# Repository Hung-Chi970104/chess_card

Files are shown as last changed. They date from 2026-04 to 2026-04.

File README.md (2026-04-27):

# Pico Chess Card
Ever think of playing chess on the size of a business card? Welcome to the Pico Chess Card!

After building my Tic-Tac-Toe business card, I decided to build a more advanced version that allows users to play chess, compete online through radio, and even compete against AI!

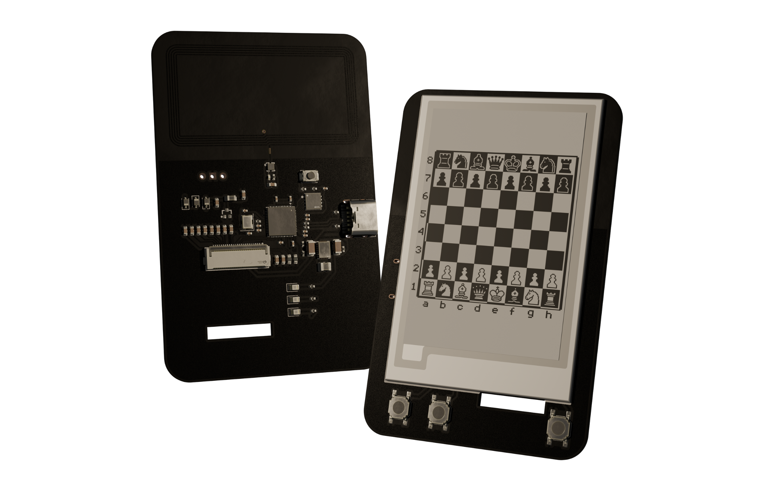
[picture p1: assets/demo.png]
demo


https://github.com/user-attachments/assets/676e2b21-aca0-44f8-8b26-b48a64608b89

# Features
- Pass-and-play mode (like one device but two people take turn)
- Online 1v1 through nrf24l01 (*Will be added in V2!)
- NFC tap to either go to websites or pairing mode

# Components
- RP2040
- 12MHz Crystal (ABM8-272-T3)
- 8MB Flash Storage (W25Q64JVXGIQ)
- Buck-Boost Switching Regulator (RT6150B)
- USB-C (TYPE-C-31-M-12)

# PCB Designs
- 2 layers
- Single-sided component placement
- 2.6mm board thickness
- HASL (with lead) surface finish
- 1oz outer copper weight

## PCB Schematic
schemtatic

## PCB Layouts
pcb_front
pcb_back
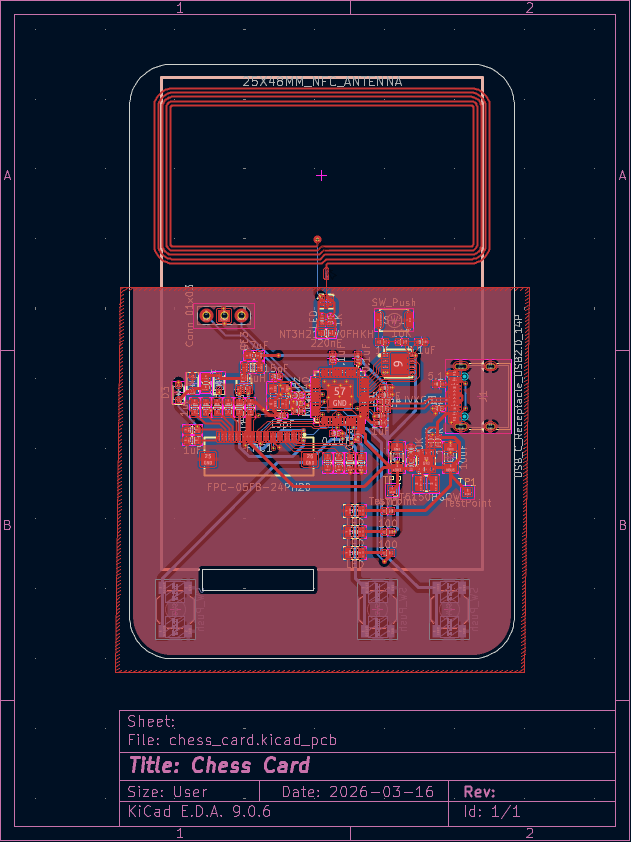
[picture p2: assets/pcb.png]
pcb_design


## 3D Model
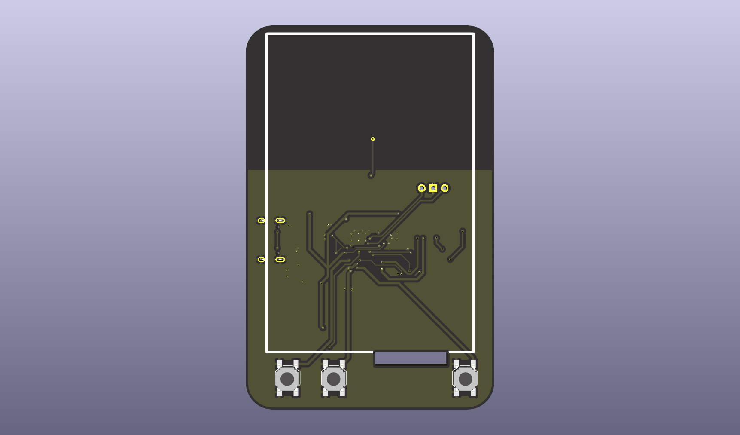
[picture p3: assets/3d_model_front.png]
3d_model_front

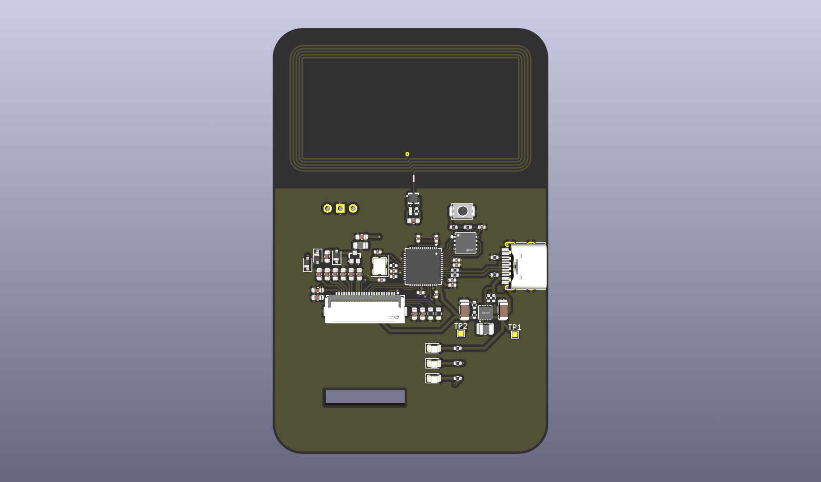
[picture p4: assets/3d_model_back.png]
3d_model_back


# How to order
- Download the zip file
- Upload the zip file to JLCPCB
- Select PCBA and continue
- Upload BOM.csv and position.csv
- Select the parts and submit payment

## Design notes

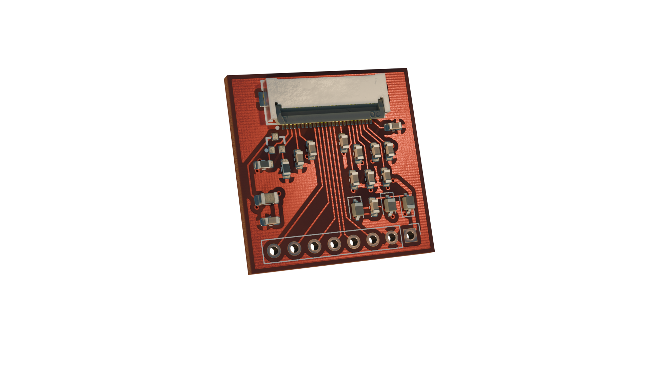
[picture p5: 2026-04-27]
e_ink_screen_module/e_ink_screen_module.png

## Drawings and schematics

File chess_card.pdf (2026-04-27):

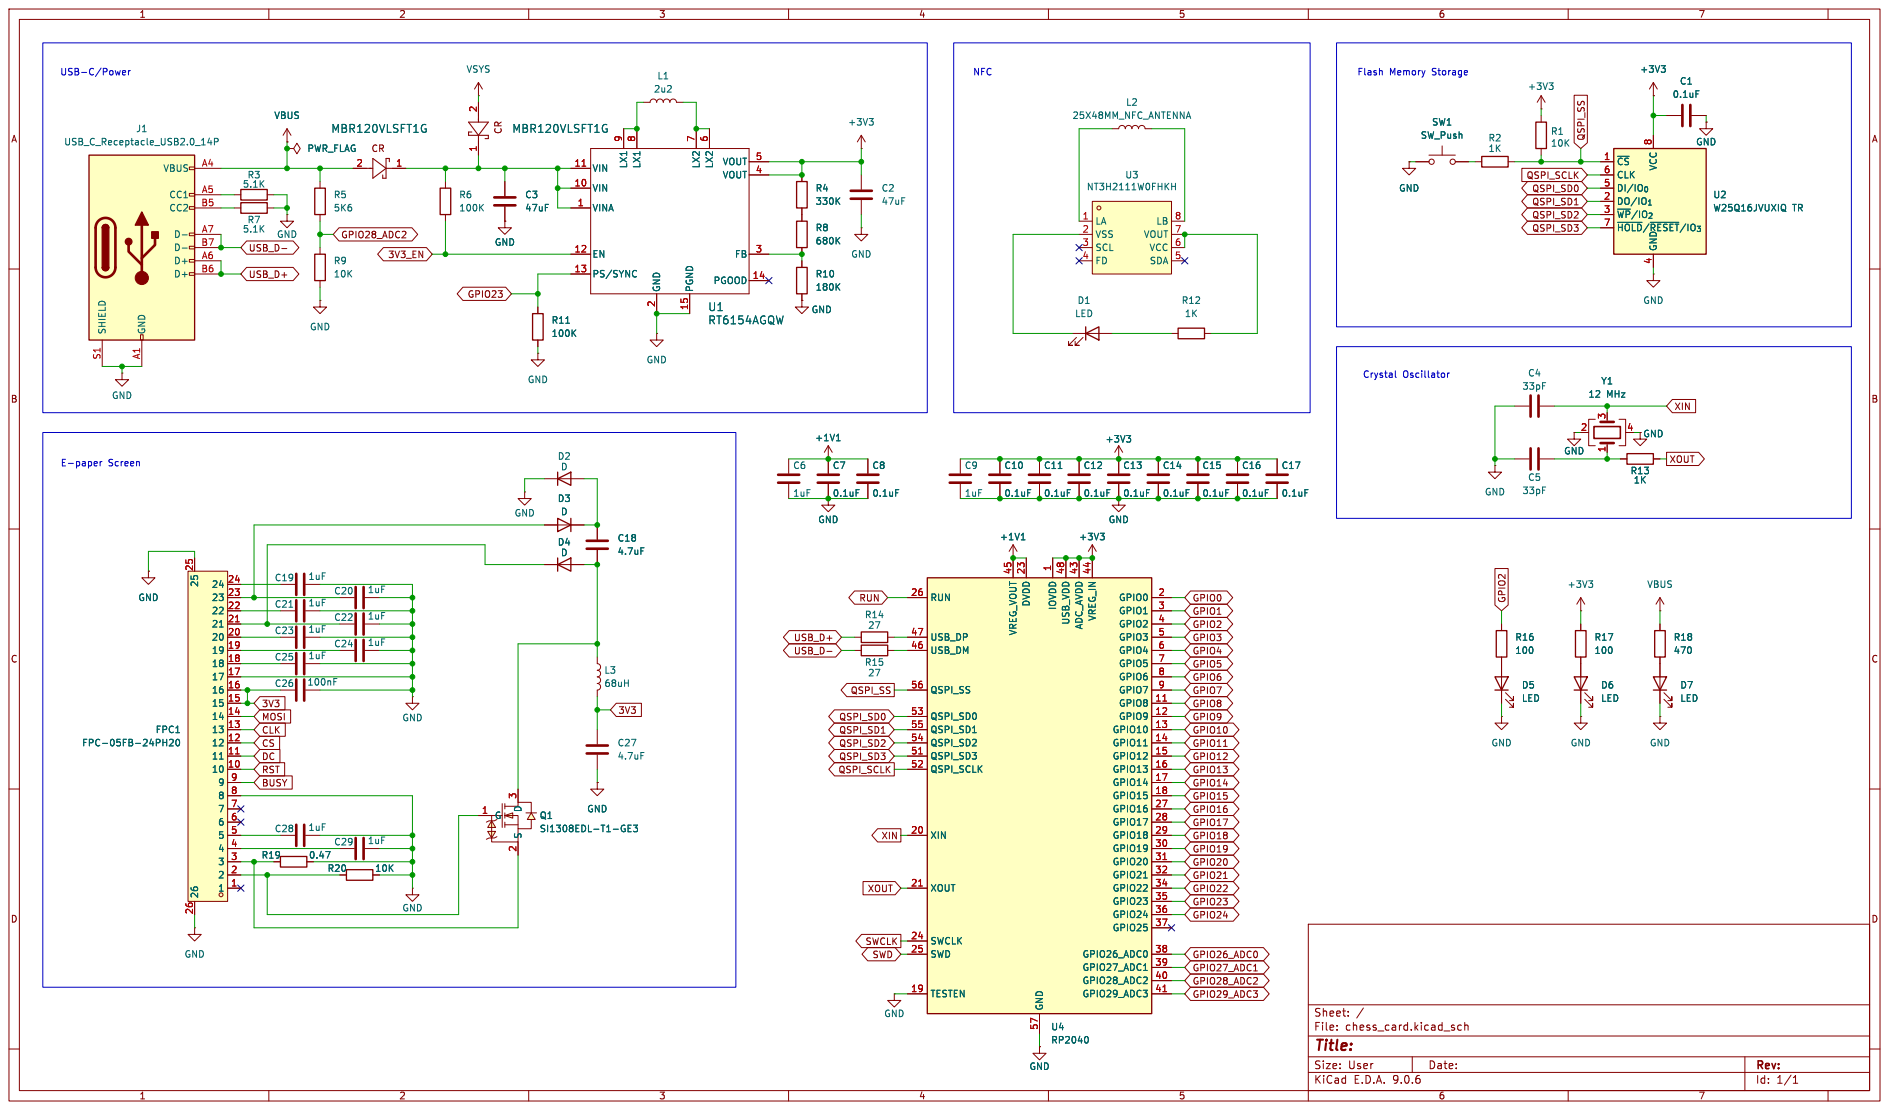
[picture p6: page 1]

6 VOUT 5 VOUT 4 FB 3 PGOOD 14 U1 RT6154AGQW

6 VOUT 5 VOUT 4 FB 3 PGOOD 14 R8

Id: 1/1 Title: File: chess_card.kicad_sch Sheet: /

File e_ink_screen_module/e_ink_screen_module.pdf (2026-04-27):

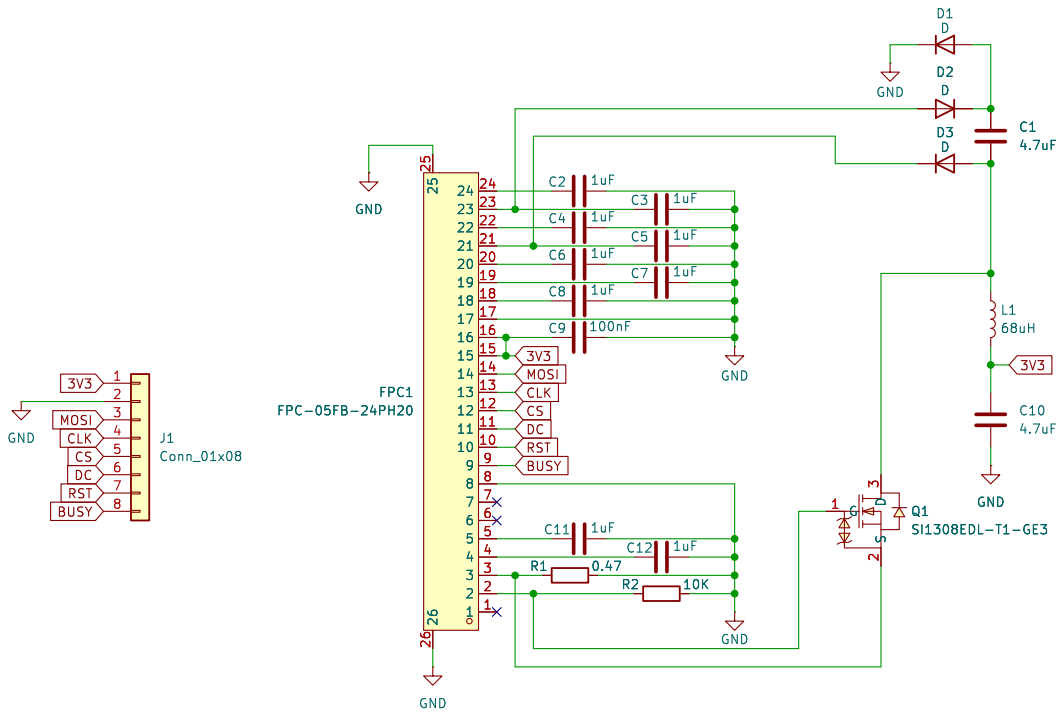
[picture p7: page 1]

Id: 1/1 Title: File: e_ink_screen_module.kicad_sch Sheet: /

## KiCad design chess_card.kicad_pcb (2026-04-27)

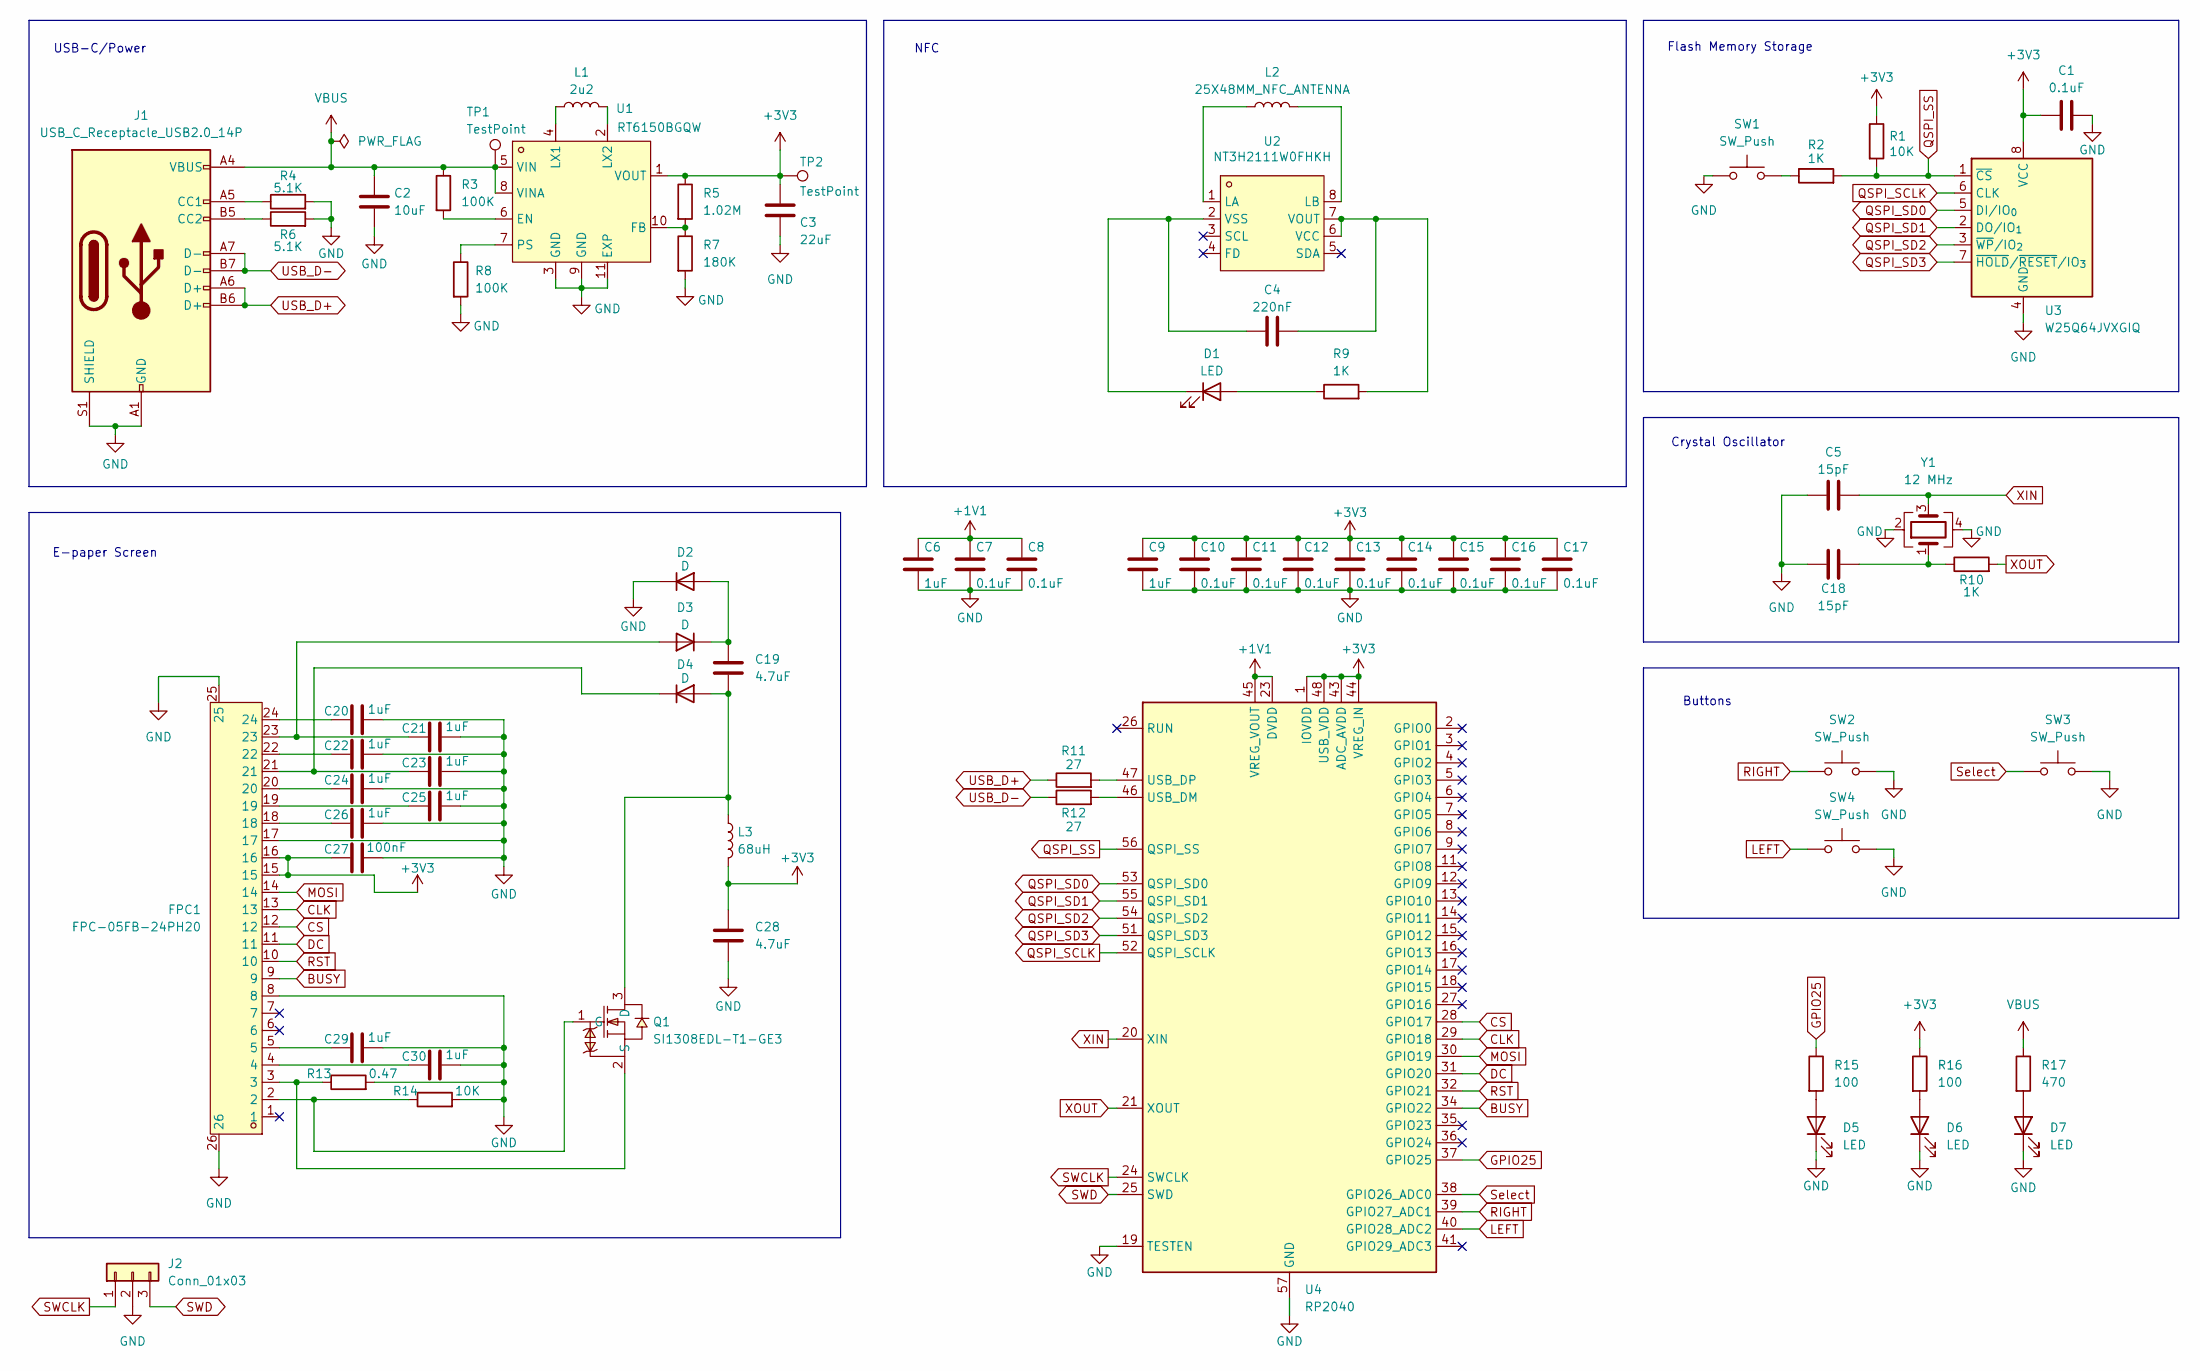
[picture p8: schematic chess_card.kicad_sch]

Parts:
C1, C7, C8, C10, C11, C12, C13, C14, C15, C16, C17: 0.1uF; C_0402_1005Metric
C2: 10uF; C_1206_3216Metric
C3: 22uF; C_1206_3216Metric
C4: 220nF; C_0603_1608Metric
C5, C18: 15pF; C_0402_1005Metric
C6, C9: 1uF; C_0402_1005Metric
C19, C28: 4.7uF; C_0603_1608Metric
C20, C21, C22, C23, C24, C25, C26, C29, C30: 1uF; C_0603_1608Metric
C27: 100nF; C_0603_1608Metric
D1: LED; LED_0402_1005Metric
D2, D3, D4: D; D_SOD-323
D5, D6, D7: LED; LED_0805_2012Metric
FPC1: FPC-05FB-24PH20; FPC-SMD_24P-P0.50_FPC-05FB-24PH20; LCSC Part C2856831
J1: USB_C_Receptacle_USB2.0_14P; USB_C_Receptacle_HRO_TYPE-C-31-M-12
J2: Conn_01x03; PinHeader_1x03_P2.54mm_Vertical
L1: 2u2; L_1008_2520Metric
L2: 25X48MM_NFC_ANTENNA
L3: 68uH; L_0805_2012Metric
Q1: SI1308EDL-T1-GE3; SOT-323_L2.0-W1.3-P1.30-LS2.1-BR; LCSC Part C469327
R1: 10K; R_0402_1005Metric
R2, R10: 1K; R_0402_1005Metric
R3, R8: 100K; R_0402_1005Metric
R4, R6: 5.1K; R_0402_1005Metric
R5: 1.02M; R_0402_1005Metric
R7: 180K; R_0402_1005Metric
R9: 1K; R_0402_1005Metric; LCSC C23182
R11, R12: 27; R_0402_1005Metric
R13: 0.47; R_0603_1608Metric
R14: 10K; R_0603_1608Metric
R15, R16: 100; R_0402_1005Metric
R17: 470; R_0402_1005Metric
SW1: SW_Push; SW_Push_SPST_NO_Alps_SKRK
SW2, SW3, SW4: SW_Push; SW_SPST_SKQG_WithoutStem
TP1, TP2: TestPoint; TestPoint_Pad_1.0x1.0mm
U1: RT6150BGQW; WSON-10_L2.5-W2.5-P0.50-BL-EP; LCSC Part C147972
U2: NT3H2111W0FHKH; XQFN-8_L1.6-W1.6-P0.50-BL_NT3H2111W0FHKH; LCSC C710403
U3: W25Q64JVXGIQ; XSON-8_L4.0-W4.0-P0.80-TL-EP
U4: RP2040; QFN-56-1EP_7x7mm_P0.4mm_EP3.2x3.2mm
Y1: 12 MHz; Crystal_SMD_3225-4Pin_3.2x2.5mm

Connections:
+1V1: C6.1, C7.1, C8.1, U4.23 (DVDD), U4.45 (VREG_VOUT), U4.50 (DVDD)
+3V3: C1.1, C3.1, C9.1, C10.1, C11.1, C12.1, C13.1, C14.1, C15.1, C16.1, C17.1, C27.2, C28.1, FPC1.15, FPC1.16, L3.2, R1.1, R5.1, R16.1, TP2.1, U1.1 (VOUT), U3.8 (VCC), U4.1 (IOVDD), U4.10 (IOVDD), U4.22 (IOVDD), U4.33 (IOVDD), U4.42 (IOVDD), U4.43 (ADC_AVDD), U4.44 (VREG_IN), U4.48 (USB_VDD), U4.49 (IOVDD)
BUSY: FPC1.9, U4.34 (GPIO22)
CLK: FPC1.13, U4.29 (GPIO18)
CS: FPC1.12, U4.28 (GPIO17)
DC: FPC1.11, U4.31 (GPIO20)
GND: C1.2, C2.2, C3.2, C5.1, C6.2, C7.2, C8.2, C9.2, C10.2, C11.2, C12.2, C13.2, C14.2, C15.2, C16.2, C17.2, C18.1, C20.1, C21.1, C22.1, C23.1, C24.1, C25.1, C26.1, C27.1, C28.2, C29.1, C30.1, D2.1 (K), D5.1 (K), D6.1 (K), D7.1 (K), FPC1.8, FPC1.17, FPC1.25, FPC1.26, J1.A1 (GND), J1.A12 (GND), J1.B1 (GND), J1.B12 (GND), J1.S1 (SHIELD), J2.2, R4.2, R6.2, R7.2, R8.2, R13.2, R14.2, SW1.1, SW2.2, SW3.2, SW4.2, U1.3 (GND), U1.9 (GND), U1.11 (EXP), U3.4 (GND), U4.19 (TESTEN), U4.57 (GND), Y1.2, Y1.4
GPIO25: R15.1, U4.37 (GPIO25)
LEFT: SW4.1, U4.40 (GPIO28_ADC2)
MOSI: FPC1.14, U4.30 (GPIO19)
unnamed: C18.2, R10.1, Y1.1
unnamed: C20.2, FPC1.24
unnamed: C22.2, FPC1.22
unnamed: C24.2, FPC1.20
unnamed: C25.2, FPC1.19
unnamed: C26.2, FPC1.18
unnamed: C29.2, FPC1.5
unnamed: C30.2, FPC1.4
unnamed: D1.2 (A), R9.1
unnamed: C4.1, D1.1 (K), U2.2 (VSS)
unnamed: C19.1, D2.2 (A), D3.1 (K)
unnamed: C21.2, D3.2 (A), FPC1.23
unnamed: C19.2, D4.2 (A), L3.1, Q1.3 (D)
unnamed: C23.2, D4.1 (K), FPC1.21
unnamed: D5.2 (A), R15.2
unnamed: D6.2 (A), R16.2
unnamed: D7.2 (A), R17.2
unnamed: J1.A5 (CC1), R4.1
unnamed: J1.B5 (CC2), R6.1
unnamed: FPC1.2, Q1.1 (G), R14.1
unnamed: FPC1.3, Q1.2 (S), R13.1
unnamed: R2.1, SW1.2
unnamed: R3.2, U1.6 (EN)
unnamed: R5.2, R7.1, U1.10 (FB)
unnamed: L1.1, U1.4 (LX1)
unnamed: L1.2, U1.2 (LX2)
unnamed: R8.1, U1.7 (PS)
unnamed: L2.1, U2.1 (LA)
unnamed: L2.2, U2.8 (LB)
unnamed: C4.2, R9.2, U2.6 (VCC), U2.7 (VOUT)
unnamed: R12.2, U4.46 (USB_DM)
unnamed: R11.2, U4.47 (USB_DP)
QSPI_SCLK: U3.6 (CLK), U4.52 (QSPI_SCLK)
QSPI_SD0: U3.5 (DI/IO_{0}), U4.53 (QSPI_SD0)
QSPI_SD1: U3.2 (DO/IO_{1}), U4.55 (QSPI_SD1)
QSPI_SD2: U3.3 (~WP/IO_{2}), U4.54 (QSPI_SD2)
QSPI_SD3: U3.7 (~HOLD/~RESET/IO_{3}), U4.51 (QSPI_SD3)
QSPI_SS: R1.2, R2.2, U3.1 (~CS), U4.56 (QSPI_SS)
RIGHT: SW2.1, U4.39 (GPIO27_ADC1)
RST: FPC1.10, U4.32 (GPIO21)
SWCLK: J2.1, U4.24 (SWCLK)
SWD: J2.3, U4.25 (SWD)
Select: SW3.1, U4.38 (GPIO26_ADC0)
USB_D+: J1.A6 (D+), J1.B6 (D+), R11.1
USB_D-: J1.A7 (D-), J1.B7 (D-), R12.1
VBUS: C2.1, J1.A4 (VBUS), J1.A9 (VBUS), J1.B4 (VBUS), J1.B9 (VBUS), R3.1, R17.1, TP1.1, U1.5 (VIN), U1.8 (VINA)
XIN: C5.2, U4.20 (XIN), Y1.3
XOUT: R10.2, U4.21 (XOUT)

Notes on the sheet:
E-paper Screen
Crystal Oscillator
Flash Memory Storage
Buttons
NFC
USB-C/Power

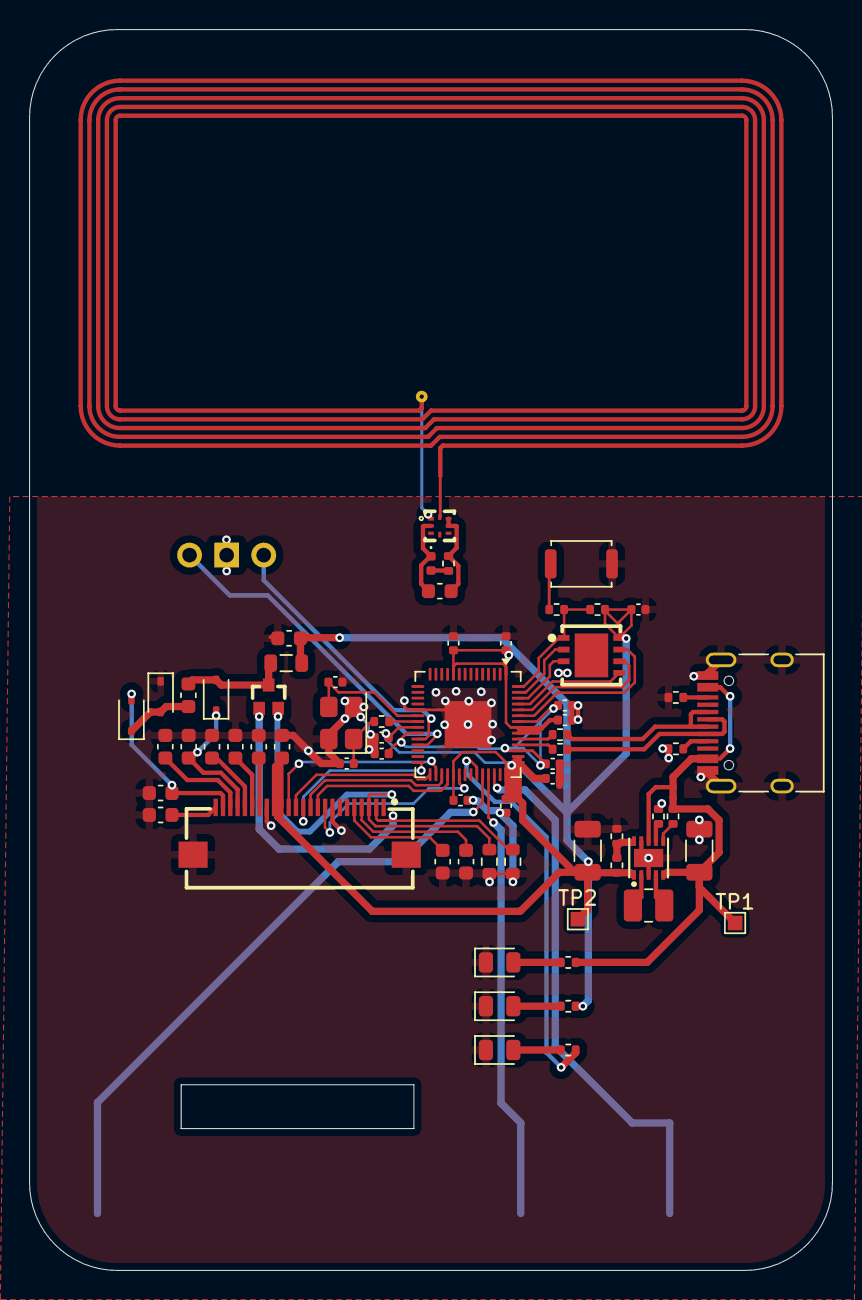
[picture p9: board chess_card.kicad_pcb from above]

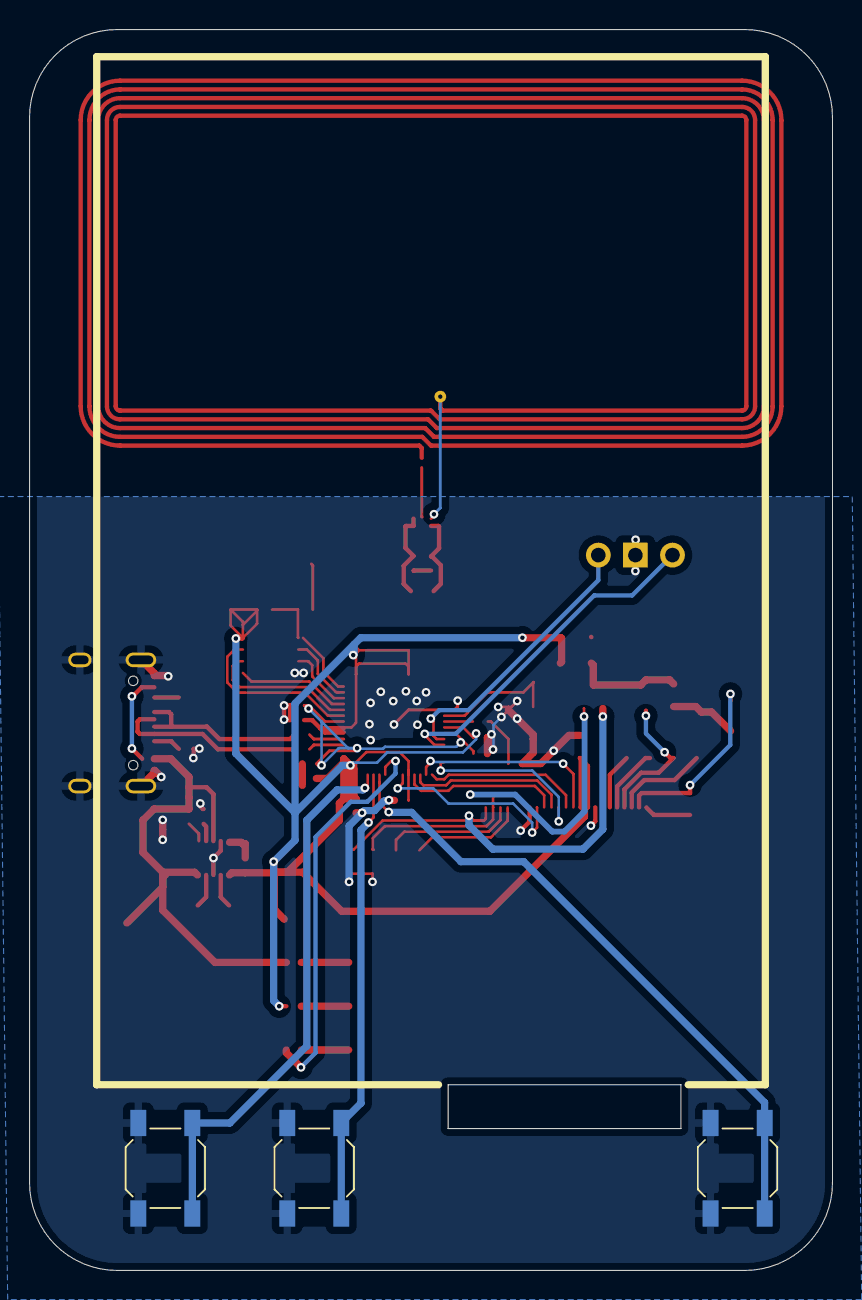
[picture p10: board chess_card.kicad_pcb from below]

Board: 2 copper layers, 55.0 x 85.0 mm, 70 parts (3 on the bottom side), 58 nets.

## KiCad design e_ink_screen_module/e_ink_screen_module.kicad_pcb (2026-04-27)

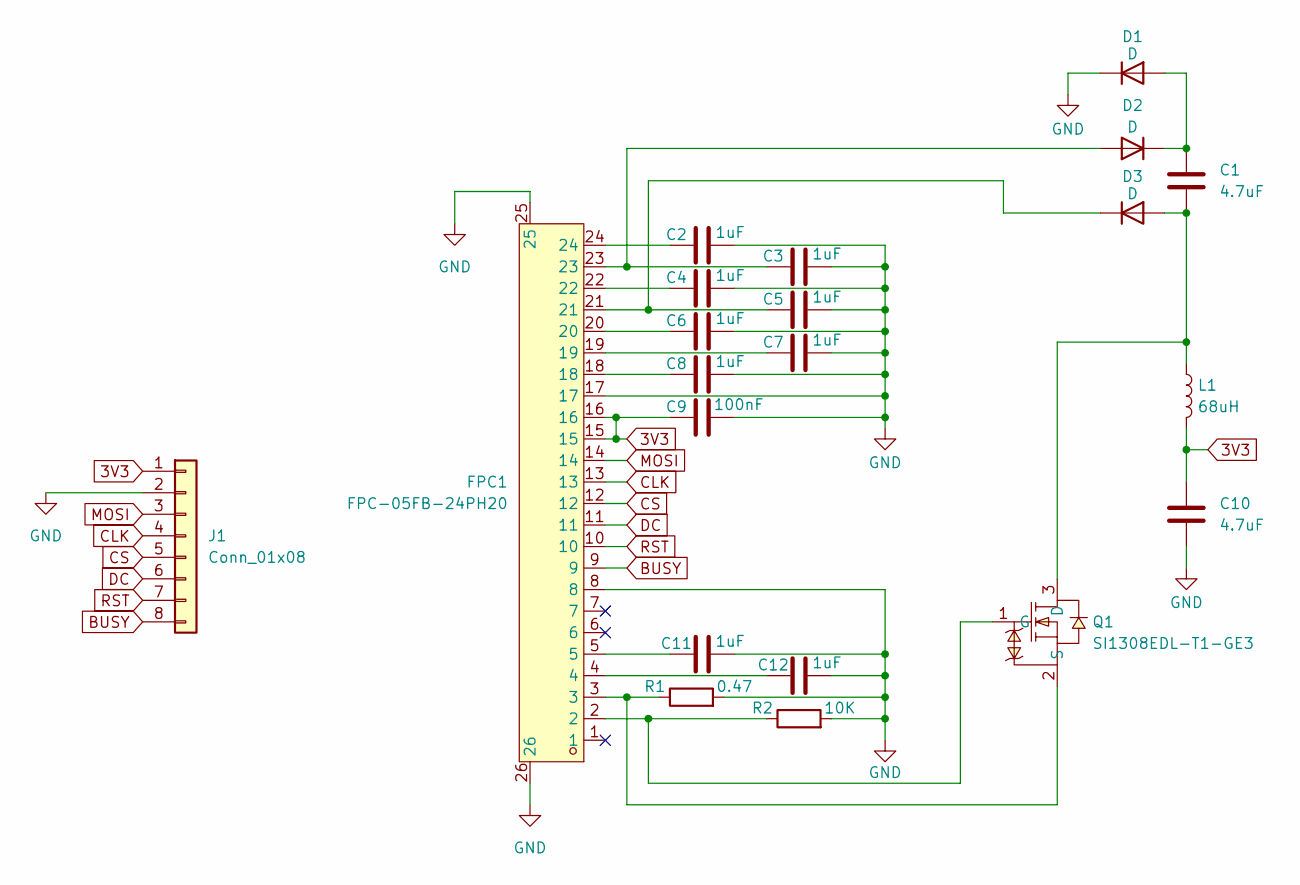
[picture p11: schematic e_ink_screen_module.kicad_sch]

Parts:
C1, C10: 4.7uF; C_0603_1608Metric
C2, C3, C4, C5, C6, C7, C8, C11, C12: 1uF; C_0603_1608Metric
C9: 100nF; C_0603_1608Metric
D1, D2, D3: D; D_SOD-323
FPC1: FPC-05FB-24PH20; FPC-SMD_24P-P0.50_FPC-05FB-24PH20; LCSC Part C2856831
J1: Conn_01x08; PinHeader_1x08_P2.54mm_Vertical
L1: 68uH; L_0805_2012Metric
Q1: SI1308EDL-T1-GE3; SOT-323_L2.0-W1.3-P1.30-LS2.1-BR; LCSC Part C469327
R1: 0.47; R_0603_1608Metric
R2: 10K; R_0603_1608Metric

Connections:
3V3: C9.2, C10.1, FPC1.15, FPC1.16, J1.1, L1.2
BUSY: FPC1.9, J1.8
CLK: FPC1.13, J1.4
CS: FPC1.12, J1.5
DC: FPC1.11, J1.6
GND: C2.1, C3.1, C4.1, C5.1, C6.1, C7.1, C8.1, C9.1, C10.2, C11.1, C12.1, D1.1 (K), FPC1.8, FPC1.17, FPC1.25, FPC1.26, J1.2, R1.2, R2.2
MOSI: FPC1.14, J1.3
unnamed: C2.2, FPC1.24
unnamed: C4.2, FPC1.22
unnamed: C6.2, FPC1.20
unnamed: C7.2, FPC1.19
unnamed: C8.2, FPC1.18
unnamed: C11.2, FPC1.5
unnamed: C12.2, FPC1.4
unnamed: C1.1, D1.2 (A), D2.1 (K)
unnamed: C3.2, D2.2 (A), FPC1.23
unnamed: C1.2, D3.2 (A), L1.1, Q1.3 (D)
unnamed: C5.2, D3.1 (K), FPC1.21
unnamed: FPC1.2, Q1.1 (G), R2.1
unnamed: FPC1.3, Q1.2 (S), R1.1
RST: FPC1.10, J1.7

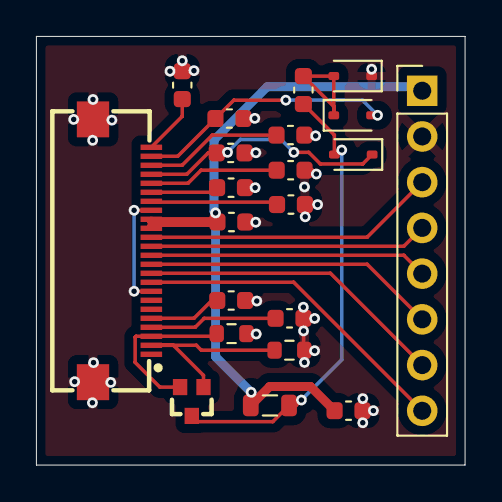
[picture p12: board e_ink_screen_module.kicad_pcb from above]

Board: 2 copper layers, 23.8 x 23.8 mm, 21 parts (0 on the bottom side), 21 nets.

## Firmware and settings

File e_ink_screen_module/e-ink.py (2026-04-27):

from micropython import const
from machine import Pin, SPI
import framebuf
import time

# =========================================================
# 1. E-PAPER DRIVER CLASS (Merged to prevent import errors)
# =========================================================
EPD_WIDTH  = const(176)
EPD_HEIGHT = const(264)

PANEL_SETTING               = const(0x00)
POWER_SETTING               = const(0x01)
POWER_ON                    = const(0x04)
BOOSTER_SOFT_START          = const(0x06)
DEEP_SLEEP                  = const(0x07)
DATA_START_TRANSMISSION_1   = const(0x10)
DISPLAY_REFRESH             = const(0x12)
DATA_START_TRANSMISSION_2   = const(0x13)
PARTIAL_DISPLAY_REFRESH     = const(0x16)
LUT_FOR_VCOM                = const(0x20)
LUT_WHITE_TO_WHITE          = const(0x21)
LUT_BLACK_TO_WHITE          = const(0x22)
LUT_WHITE_TO_BLACK          = const(0x23)
LUT_BLACK_TO_BLACK          = const(0x24)
PLL_CONTROL                 = const(0x30)
VCM_DC_SETTING_REGISTER     = const(0x82)
POWER_OPTIMIZATION          = const(0xF8)

BUSY = const(0)

class EPD:
    def __init__(self, spi, cs, dc, rst, busy):
        self.spi = spi
        self.cs = cs
        self.dc = dc
        self.rst = rst
        self.busy = busy
        self.cs.init(self.cs.OUT, value=1)
        self.dc.init(self.dc.OUT, value=0)
        self.rst.init(self.rst.OUT, value=0)
        self.busy.init(self.busy.IN)
        self.width = EPD_WIDTH
        self.height = EPD_HEIGHT

    LUT_VCOM_DC = bytearray(b'\x00\x00\x00\x0F\x0F\x00\x00\x05\x00\x32\x32\x00\x00\x02\x00\x0F\x0F\x00\x00\x05\x00\x00\x00\x00\x00\x00\x00\x00\x00\x00\x00\x00\x00\x00\x00\x00\x00\x00\x00\x00\x00\x00\x00\x00')
    LUT_WW      = bytearray(b'\x50\x0F\x0F\x00\x00\x05\x60\x32\x32\x00\x00\x02\xA0\x0F\x0F\x00\x00\x05\x00\x00\x00\x00\x00\x00\x00\x00\x00\x00\x00\x00\x00\x00\x00\x00\x00\x00\x00\x00\x00\x00\x00\x00')
    LUT_BW      = bytearray(b'\x50\x0F\x0F\x00\x00\x05\x60\x32\x32\x00\x00\x02\xA0\x0F\x0F\x00\x00\x05\x00\x00\x00\x00\x00\x00\x00\x00\x00\x00\x00\x00\x00\x00\x00\x00\x00\x00\x00\x00\x00\x00\x00\x00')
    LUT_BB      = bytearray(b'\xA0\x0F\x0F\x00\x00\x05\x60\x32\x32\x00\x00\x02\x50\x0F\x0F\x00\x00\x05\x00\x00\x00\x00\x00\x00\x00\x00\x00\x00\x00\x00\x00\x00\x00\x00\x00\x00\x00\x00\x00\x00\x00\x00')
    LUT_WB      = LUT_BB
    
    def _command(self, command, data=None):
        self.dc(0)
        self.cs(0)
        self.spi.write(bytearray([command]))
        self.cs(1)
        if data is not None:
            self._data(data)

    def _data(self, data):
        self.dc(1)
        self.cs(0)
        self.spi.write(data)
        self.cs(1)

    def init(self):
        self.reset()
        self._command(POWER_SETTING, b'\x03\x00\x2B\x2B\x09')
        self._command(BOOSTER_SOFT_START, b'\x07\x07\x17')
        self._command(POWER_OPTIMIZATION, b'\x60\xA5')
        self._command(POWER_OPTIMIZATION, b'\x89\xA5')
        self._command(POWER_OPTIMIZATION, b'\x90\x00')
        self._command(POWER_OPTIMIZATION, b'\x93\x2A')
        self._command(POWER_OPTIMIZATION, b'\xA0\xA5')
        self._command(POWER_OPTIMIZATION, b'\xA1\x00')
        self._command(POWER_OPTIMIZATION, b'\x73\x41')
        self._command(PARTIAL_DISPLAY_REFRESH, b'\x00')
        self._command(POWER_ON)
        self.wait_until_idle()
        self._command(PANEL_SETTING, b'\xAF')
        self._command(PLL_CONTROL, b'\x3A')
        self._command(VCM_DC_SETTING_REGISTER, b'\x12')
        time.sleep_ms(2)
        self.set_lut()

    def wait_until_idle(self):
        while self.busy.value() == BUSY:
            time.sleep_ms(100)

    def reset(self):
        self.rst(0)
        time.sleep_ms(200)
        self.rst(1)
        time.sleep_ms(200)

    def set_lut(self):
        self._command(LUT_FOR_VCOM, self.LUT_VCOM_DC)
        self._command(LUT_WHITE_TO_WHITE, self.LUT_WW)
        self._command(LUT_BLACK_TO_WHITE, self.LUT_BW)
        self._command(LUT_WHITE_TO_BLACK, self.LUT_BB)
        self._command(LUT_BLACK_TO_BLACK, self.LUT_WB)

    def display_frame(self, frame_buffer):
        if (frame_buffer != None):
            self._command(DATA_START_TRANSMISSION_1)
            time.sleep_ms(2)
            for i in range(0, self.width * self.height // 8):
                self._data(bytearray([0xFF]))
            time.sleep_ms(2)
            self._command(DATA_START_TRANSMISSION_2)
            time.sleep_ms(2)
            for i in range(0, self.width * self.height // 8):
                self._data(bytearray([frame_buffer[i]]))
            time.sleep_ms(2)
            self._command(DISPLAY_REFRESH)
            self.wait_until_idle()

    def sleep(self):
        self._command(DEEP_SLEEP, b'\xA5')


# =========================================================
# 2. HARDWARE SETUP
# =========================================================
print("Setting up hardware...")

# SPI and E-Paper Pins (Pico example)
spi = SPI(0, baudrate=20000000, polarity=0, phase=0, sck=Pin(18), mosi=Pin(19))

# E-Paper Control Pins
cs = Pin(17)    # EPD_CS
dc = Pin(20)    # EPD_DC
rst = Pin(21)   # EPD_RST
busy = Pin(22)  # EPD_BUSY

# Initialize the display object
epd = EPD(spi, cs, dc, rst, busy)

# Framebuffer Setup
width = epd.width   
height = epd.height 
buffer = bytearray(width * height // 8) 
fb = framebuf.FrameBuffer(buffer, width, height, framebuf.MONO_HLSB)

# Button Pins (Connected to Ground when pressed)
btn_up = Pin(2, Pin.IN, Pin.PULL_UP)
btn_down = Pin(3, Pin.IN, Pin.PULL_UP)
btn_left = Pin(4, Pin.IN, Pin.PULL_UP)
btn_right = Pin(5, Pin.IN, Pin.PULL_UP)

# =========================================================
# 3. DRAWING FUNCTION
# =========================================================
def draw_board(fb, cursor_x, cursor_y):
    SQUARE_SIZE = 22
    fb.fill(1) # Wipe background to White (1)
    
    # Draw the 8x8 checkerboard pattern
    for row in range(8):
        for col in range(8):
            x = col * SQUARE_SIZE
            y = row * SQUARE_SIZE
            
            # Alternating colors: If row+col is odd, fill with Black (0)
            if (row + col) % 2 == 1:
                fb.fill_rect(x, y, SQUARE_SIZE, SQUARE_SIZE, 0)
            
            # Draw a black border around EVERY square
            fb.rect(x, y, SQUARE_SIZE, SQUARE_SIZE, 0)

    # Draw the Selection Cursor (Thick double-lined box)
    cx = cursor_x * SQUARE_SIZE
    cy = cursor_y * SQUARE_SIZE
    fb.rect(cx, cy, SQUARE_SIZE, SQUARE_SIZE, 1)       
    fb.rect(cx+1, cy+1, SQUARE_SIZE-2, SQUARE_SIZE-2, 0) 
    fb.rect(cx+2, cy+2, SQUARE_SIZE-4, SQUARE_SIZE-4, 1) 
    fb.rect(cx+3, cy+3, SQUARE_SIZE-6, SQUARE_SIZE-6, 0) 

    # Draw the Bottom UI Area
    chess_col = chr(65 + cursor_x) # 65 is 'A' in ASCII
    chess_row = 8 - cursor_y
    
    fb.text("MICROPYTHON CHESS", 15, 190, 0)
    fb.hline(10, 205, 156, 0) 
    fb.text(f"Cursor: [ {chess_col}{chess_row} ]", 15, 215, 0)
    fb.text("Waiting for move...", 15, 235, 0)

# =========================================================
# 4. GAME LOOP & LOGIC
# =========================================================
cursor_x = 0
cursor_y = 0
last_input_time = time.ticks_ms()
pending_update = True 

print("Starting game loop! Press the buttons to move.")

while True:
    input_detected = False
    
    # Check buttons (0 means it is being pressed down)
    if btn_up.value() == 0:
        cursor_y = max(0, cursor_y - 1)
        input_detected = True
    elif btn_down.value() == 0:
        cursor_y = min(7, cursor_y + 1)
        input_detected = True
    elif btn_left.value() == 0:
        cursor_x = max(0, cursor_x - 1)
        input_detected = True
    elif btn_right.value() == 0:
        cursor_x = min(7, cursor_x + 1)
        input_detected = True
        
    # If a button was pressed, reset the timer and flag an update
    if input_detected:
        last_input_time = time.ticks_ms()
        pending_update = True
        time.sleep_ms(200) 
        
    # Check if we need to update AND if the user has paused for 1.5 seconds
    current_time = time.ticks_ms()
    time_since_last_press = time.ticks_diff(current_time, last_input_time)
    
    if pending_update and time_since_last_press > 1500:
        print(f"User paused. Updating screen to {chr(65+cursor_x)}{8-cursor_y}...")
        
        draw_board(fb, cursor_x, cursor_y)
        
        # Wake up the display, push the image, and put it back to sleep
        epd.init() 
        epd.display_frame(buffer)
        epd.sleep()
        
        pending_update = False 
        print("Ready for next move.")
        
    # Small delay to keep the loop from hogging the CPU
    time.sleep_ms(50)

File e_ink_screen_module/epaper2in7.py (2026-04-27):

"""
MicroPython Waveshare 2.7" Black/White GDEW027W3 e-paper display driver
https://github.com/mcauser/micropython-waveshare-epaper

MIT License
Copyright (c) 2017 Waveshare
Copyright (c) 2018 Mike Causer

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
from micropython import const
from time import sleep_ms

# Display resolution
EPD_WIDTH  = const(176)
EPD_HEIGHT = const(264)

# Display commands
PANEL_SETTING                     = const(0x00)
POWER_SETTING                     = const(0x01)
#POWER_OFF                         = const(0x02)
#POWER_OFF_SEQUENCE_SETTING        = const(0x03)
POWER_ON                          = const(0x04)
#POWER_ON_MEASURE                  = const(0x05)
BOOSTER_SOFT_START                = const(0x06)
DEEP_SLEEP                        = const(0x07)
DATA_START_TRANSMISSION_1         = const(0x10)
#DATA_STOP                         = const(0x11)
DISPLAY_REFRESH                   = const(0x12)
DATA_START_TRANSMISSION_2         = const(0x13) # not in datasheet
#PARTIAL_DATA_START_TRANSMISSION_1 = const(0x14)
#PARTIAL_DATA_START_TRANSMISSION_2 = const(0x15)
PARTIAL_DISPLAY_REFRESH           = const(0x16)
LUT_FOR_VCOM                      = const(0x20) # LUT for VCOM(LUT1)
LUT_WHITE_TO_WHITE                = const(0x21) # White to white LUT (LUTWW)
LUT_BLACK_TO_WHITE                = const(0x22) # Black to white LUT (LUTBW/LUTR)
LUT_WHITE_TO_BLACK                = const(0x23) # White to Black LUT (LUTWB/LUTW)
LUT_BLACK_TO_BLACK                = const(0x24) # Black to Black LUT (LUTBB/LUTB)
PLL_CONTROL                       = const(0x30)
#TEMPERATURE_SENSOR_COMMAND        = const(0x40)
#TEMPERATURE_SENSOR_CALIBRATION    = const(0x41)
#TEMPERATURE_SENSOR_WRITE          = const(0x42)
#TEMPERATURE_SENSOR_READ           = const(0x43)
#VCOM_AND_DATA_INTERVAL_SETTING    = const(0x50)
#LOW_POWER_DETECTION               = const(0x51)
#TCON_SETTING                      = const(0x60)
#TCON_RESOLUTION                   = const(0x61)
#SOURCE_AND_GATE_START_SETTING     = const(0x62)
#GET_STATUS                        = const(0x71)
#AUTO_MEASURE_VCOM                 = const(0x80)
#VCOM_VALUE                        = const(0x81)
VCM_DC_SETTING_REGISTER           = const(0x82)
#PROGRAM_MODE                      = const(0xA0)
#ACTIVE_PROGRAM                    = const(0xA1)
#READ_OTP_DATA                     = const(0xA2)
POWER_OPTIMIZATION                = const(0xF8) # Power optimization in flow diagram

BUSY = const(0)  # 0=busy, 1=idle

class EPD:
    def __init__(self, spi, cs, dc, rst, busy):
        self.spi = spi
        self.cs = cs
        self.dc = dc
        self.rst = rst
        self.busy = busy
        self.cs.init(self.cs.OUT, value=1)
        self.dc.init(self.dc.OUT, value=0)
        self.rst.init(self.rst.OUT, value=0)
        self.busy.init(self.busy.IN)
        self.width = EPD_WIDTH
        self.height = EPD_HEIGHT

    LUT_VCOM_DC = bytearray(b'\x00\x00\x00\x0F\x0F\x00\x00\x05\x00\x32\x32\x00\x00\x02\x00\x0F\x0F\x00\x00\x05\x00\x00\x00\x00\x00\x00\x00\x00\x00\x00\x00\x00\x00\x00\x00\x00\x00\x00\x00\x00\x00\x00\x00\x00')
    LUT_WW      = bytearray(b'\x50\x0F\x0F\x00\x00\x05\x60\x32\x32\x00\x00\x02\xA0\x0F\x0F\x00\x00\x05\x00\x00\x00\x00\x00\x00\x00\x00\x00\x00\x00\x00\x00\x00\x00\x00\x00\x00\x00\x00\x00\x00\x00\x00') # R21H
    LUT_BW      = bytearray(b'\x50\x0F\x0F\x00\x00\x05\x60\x32\x32\x00\x00\x02\xA0\x0F\x0F\x00\x00\x05\x00\x00\x00\x00\x00\x00\x00\x00\x00\x00\x00\x00\x00\x00\x00\x00\x00\x00\x00\x00\x00\x00\x00\x00') # R22H r
    LUT_BB      = bytearray(b'\xA0\x0F\x0F\x00\x00\x05\x60\x32\x32\x00\x00\x02\x50\x0F\x0F\x00\x00\x05\x00\x00\x00\x00\x00\x00\x00\x00\x00\x00\x00\x00\x00\x00\x00\x00\x00\x00\x00\x00\x00\x00\x00\x00') # R24H b
    LUT_WB      = LUT_BB # R23H w
    
    
    def _command(self, command, data=None):
        self.dc(0)
        self.cs(0)
        self.spi.write(bytearray([command]))
        self.cs(1)
        if data is not None:
            self._data(data)

    def _data(self, data):
        self.dc(1)
        self.cs(0)
        self.spi.write(data)
        self.cs(1)

    def init(self):
        self.reset()
        self._command(POWER_SETTING, b'\x03\x00\x2B\x2B\x09') # VDS_EN VDG_EN, VCOM_HV VGHL_LV[1] VGHL_LV[0], VDH, VDL, VDHR
        self._command(BOOSTER_SOFT_START, b'\x07\x07\x17')
        self._command(POWER_OPTIMIZATION, b'\x60\xA5')
        self._command(POWER_OPTIMIZATION, b'\x89\xA5')
        self._command(POWER_OPTIMIZATION, b'\x90\x00')
        self._command(POWER_OPTIMIZATION, b'\x93\x2A')
        self._command(POWER_OPTIMIZATION, b'\xA0\xA5')
        self._command(POWER_OPTIMIZATION, b'\xA1\x00')
        self._command(POWER_OPTIMIZATION, b'\x73\x41')
        self._command(PARTIAL_DISPLAY_REFRESH, b'\x00')
        self._command(POWER_ON)
        self.wait_until_idle()
        self._command(PANEL_SETTING, b'\xAF') # KW-BF   KWR-AF    BWROTP 0f
        self._command(PLL_CONTROL, b'\x3A') # 3A 100HZ   29 150Hz 39 200HZ    31 171HZ
        self._command(VCM_DC_SETTING_REGISTER, b'\x12')
        sleep_ms(2)
        self.set_lut()

    def wait_until_idle(self):
        while self.busy.value() == BUSY:
            sleep_ms(100)

    def reset(self):
        self.rst(0)
        sleep_ms(200)
        self.rst(1)
        sleep_ms(200)

    def set_lut(self):
        self._command(LUT_FOR_VCOM, self.LUT_VCOM_DC)  # vcom
        self._command(LUT_WHITE_TO_WHITE, self.LUT_WW) # ww --
        self._command(LUT_BLACK_TO_WHITE, self.LUT_BW) # bw r
        self._command(LUT_WHITE_TO_BLACK, self.LUT_BB) # wb w
        self._command(LUT_BLACK_TO_BLACK, self.LUT_WB) # bb b

    # draw the current frame memory
    def display_frame(self, frame_buffer):
        if (frame_buffer != None):
            self._command(DATA_START_TRANSMISSION_1)
            sleep_ms(2)
            for i in range(0, self.width * self.height // 8):
                self._data(bytearray([0xFF]))
            sleep_ms(2)
            self._command(DATA_START_TRANSMISSION_2)
            sleep_ms(2)
            for i in range(0, self.width * self.height // 8):
                self._data(bytearray([frame_buffer[i]]))
            sleep_ms(2)
            self._command(DISPLAY_REFRESH)
            self.wait_until_idle()

    # to wake call reset() or init()
    def sleep(self):
        self._command(DEEP_SLEEP, b'\xA5')
